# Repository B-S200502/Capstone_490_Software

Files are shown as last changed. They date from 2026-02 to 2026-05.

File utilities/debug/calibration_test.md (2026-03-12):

# Camera–array calibration test setup

Reference for the physical layout used when testing heatmap vs camera alignment. Values are also in [config.py](../../src/software/acoustic_imager/config.py) as `CALIBRATION_*` for use in code.

## Layout

- **Camera on left**, **audio board (mic array) on right**; **same heading** (parallel).
- Camera optical axis and array “forward” (0°) are parallel; offset between them is lateral only.

## Distance

- **5 inches** — distance from camera to mic array center (depth).
- Measured along the common heading (perpendicular to the camera sensor plane).

## Lateral offset

- **7 inches** — from **camera optical center** to **center of audio board** (array center), in the plane at that depth.
- **Sign convention:** Positive = array center is to the **right** of camera center when the camera is on the left. So in this setup the array is +7 in from camera center.

## Units

- All values in **inches** here and in config for the test setup.
- Conversion to meters or to **pixels** (for overlay alignment) will need camera FOV and sensor/resolution; not defined in this doc.

## Use

- For calibration tests and for future overlay code that maps heatmap angle space to camera pixels (so the blob for the array appears over the array in the image).

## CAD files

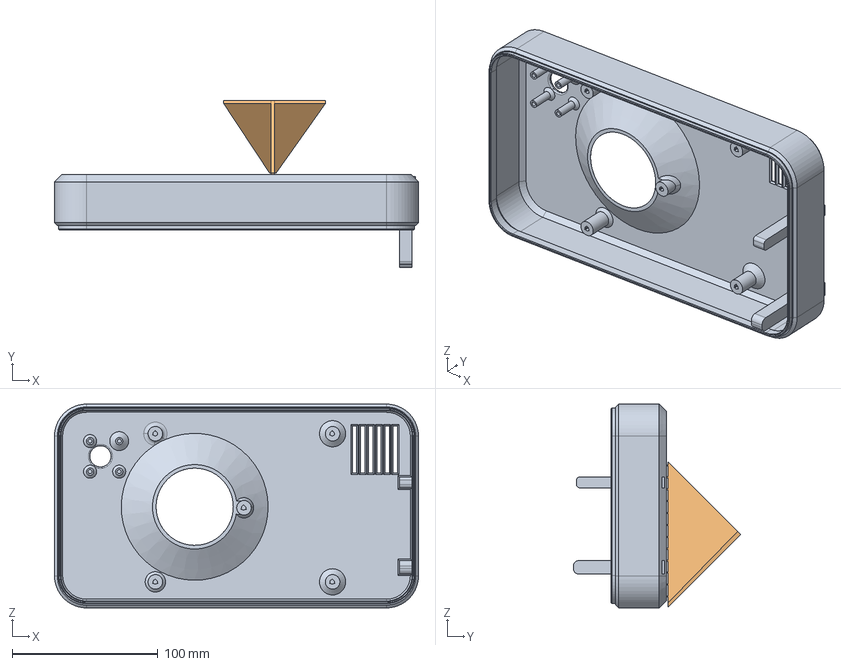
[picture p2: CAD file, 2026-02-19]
hardware/3D_Design/before_printing/BACK_TESTING.FCStd
250.0 x 114.9 x 140.0 mm
final_base_cut

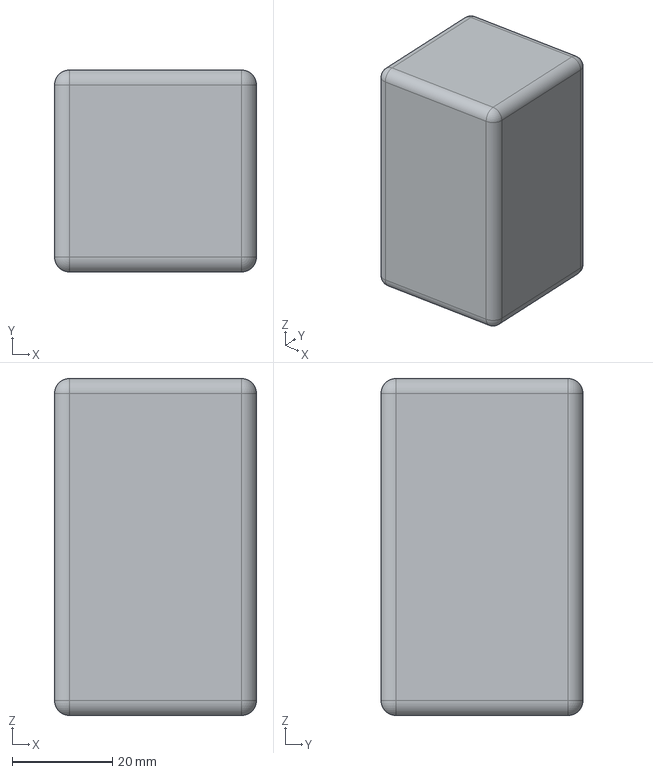
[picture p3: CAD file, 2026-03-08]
hardware/3D_Design/component_step_files/generic_BatteryPack_Envelope.step
40.4 x 40.4 x 67.4 mm

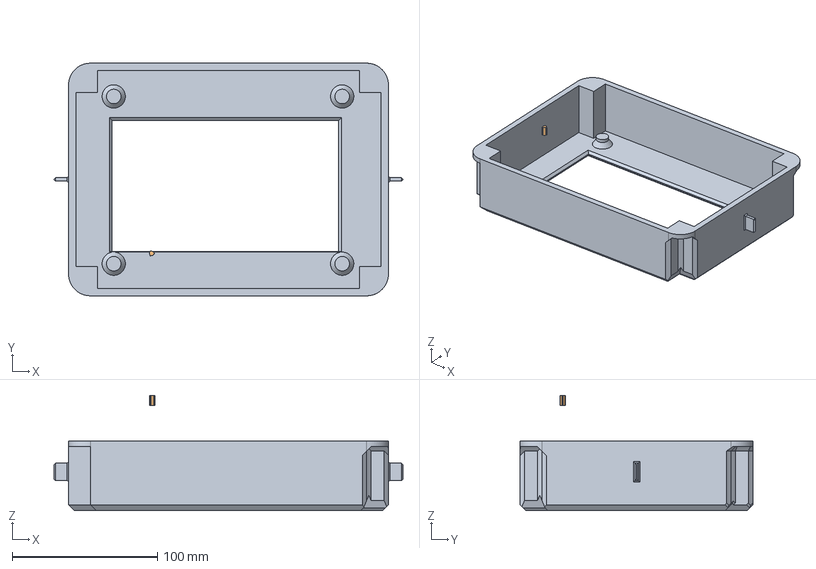
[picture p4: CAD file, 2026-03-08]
hardware/3D_Design/Imager.FCStd
240.0 x 160.0 x 79.3 mm
Front
M3_Screw002

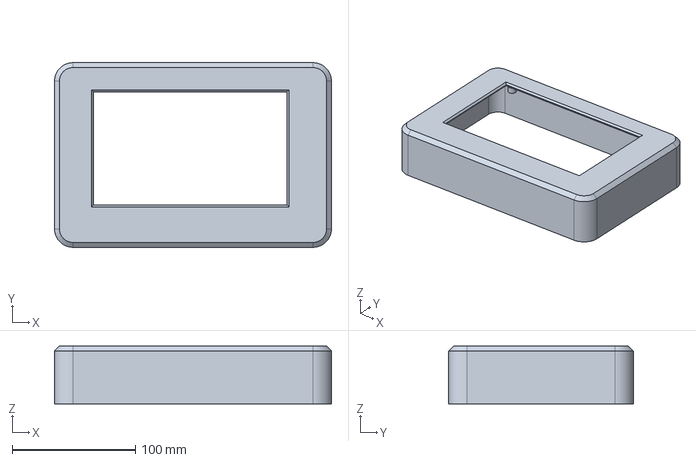
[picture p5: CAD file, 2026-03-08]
hardware/3D_Design/just_in_case_saves/V2_AC.FCStd
225.0 x 150.0 x 47.0 mm
Front
M3_Screw002

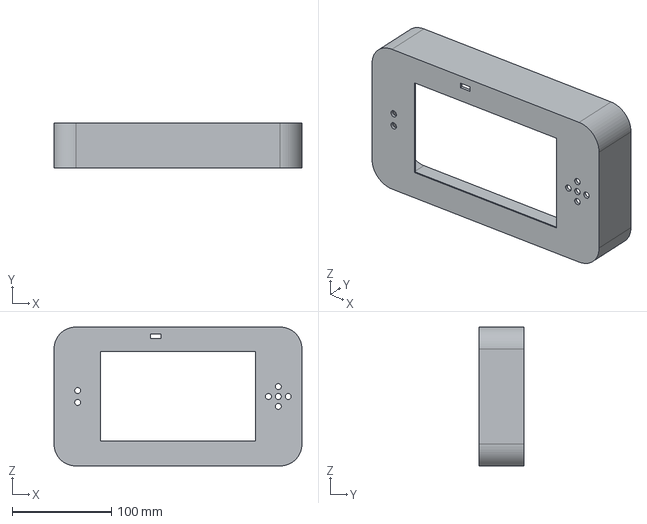
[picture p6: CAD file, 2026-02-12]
hardware/3D_Design/result_step_files/TOP-or-FRONT-AcousticImager-Fusion001.step
250.0 x 45.0 x 140.0 mm

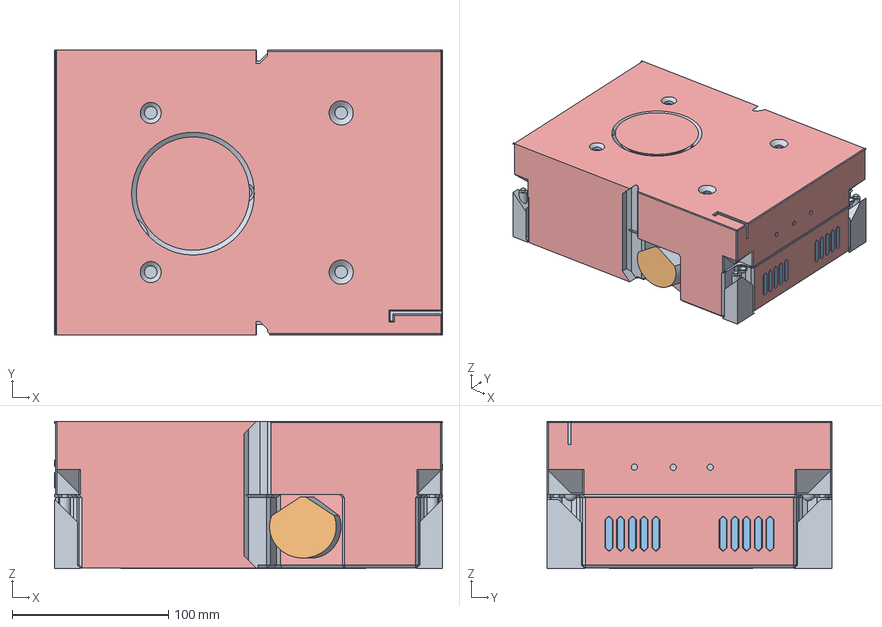
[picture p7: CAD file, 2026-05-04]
src/hardware/for_airflow/airflow.FCStd
248.0 x 182.0 x 94.0 mm
inlet
outlet
outlet001
wall

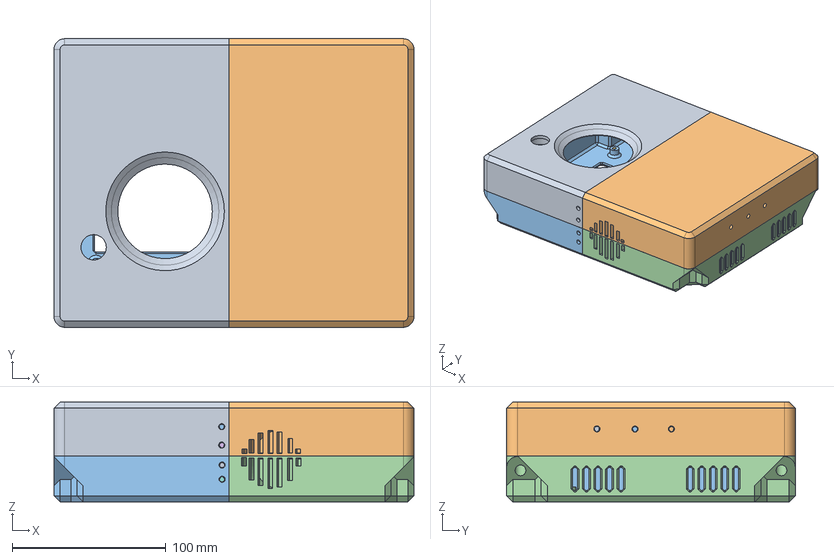
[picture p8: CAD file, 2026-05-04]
src/hardware/Front_And_Back_File/Quarters_MK3.FCStd
234.5 x 188.0 x 65.0 mm
Bottom_Left
Bottom_Right
Top_Left
Top_Right
M3_Screw_corner_ref__front_001
M3_Screw_corner_ref__front_002
M3_Screw_corner_ref__front_003
M3_Screw_corner_ref__front_004
M3_Screw_audio001
M3_Screw_audio002
M3_Screw_audio003
M3_Screw_audio004
M3_Screw_lcd001
M3_Screw_lcd002
M3_Screw_lcd003
M3_Screw_lcd004
M3_Screw_pi001
M3_Screw_pi002
M3_Screw_pi003
m4_fan_8mm001
m4_fan_8mm002
m4_fan_8mm003
m4_fan_8mm004
M2.6_cam_7mm001
M2.6_cam_7mm002
M2.6_cam_7mm003
M2.6_cam_7mm004
M3_thick_wall001
M3_thick_wall002
M3_thick_wall003
M3_thick_wall004
M3_thick_wall005
M3_thick_wall06
M3_thick_wall07
M3_thick_wall008
M3_Screw_power_wall001
M3_Screw_power_wall002
M3_Screw_power_wall003

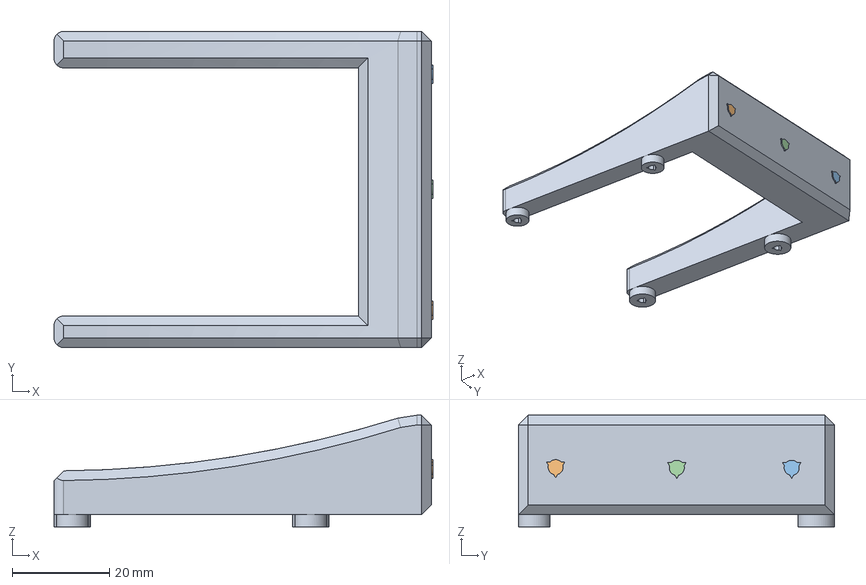
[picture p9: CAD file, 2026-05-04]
src/hardware/Pi_Base/Pi_Base_Support.FCStd
77.9 x 65.0 x 22.9 mm
before_side_screws
M3_Screw_pi001
M3_Screw_pi002
M3_Screw_pi003

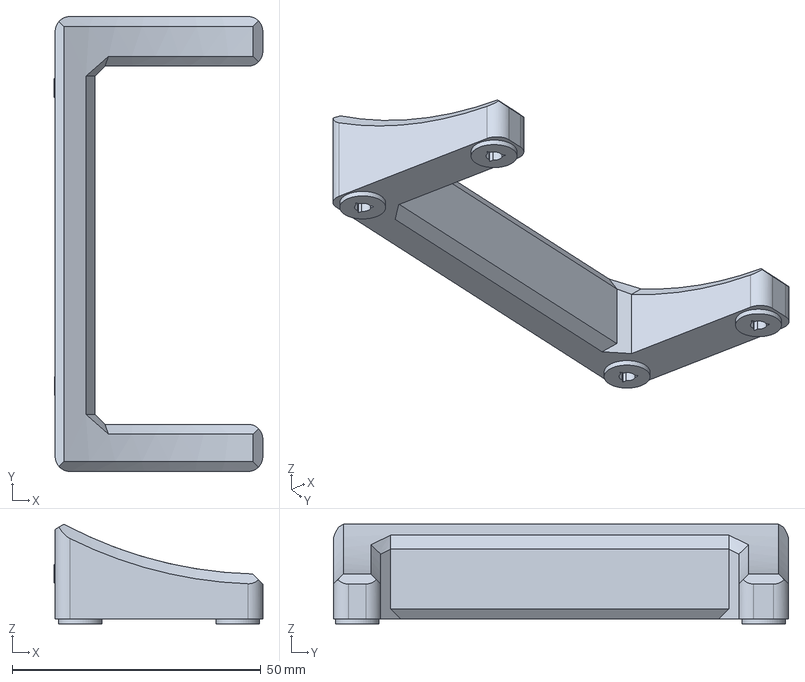
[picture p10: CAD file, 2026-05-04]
src/hardware/Power_Base/PowerBoard_Support_Stand.FCStd
42.0 x 91.5 x 20.0 mm
before_side_wall_screws
M3_Screw_power_wall001
M3_Screw_power_wall002
M3_Screw_power_wall003

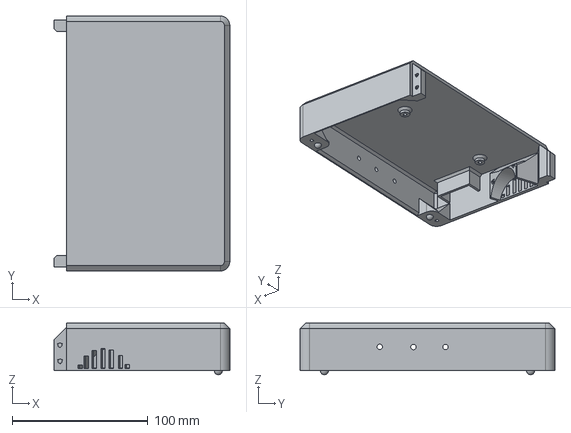
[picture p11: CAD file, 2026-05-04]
src/hardware/result_step_files/bottom/BR_low_fan.step
129.5 x 188.0 x 38.0 mm

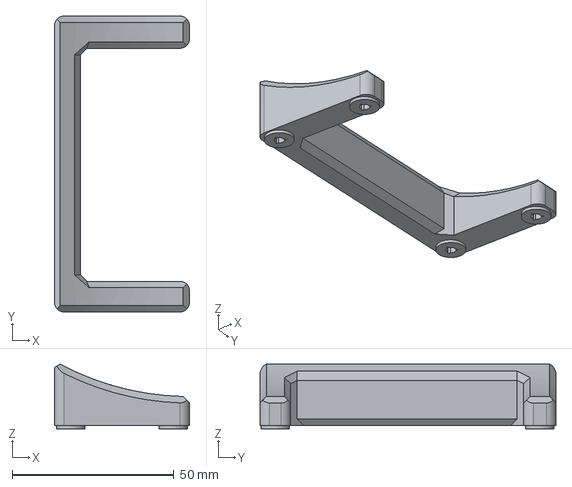
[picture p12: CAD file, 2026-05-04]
src/hardware/result_step_files/power_base/PowerBoard_Support_Stand.step
41.8 x 91.5 x 20.0 mm

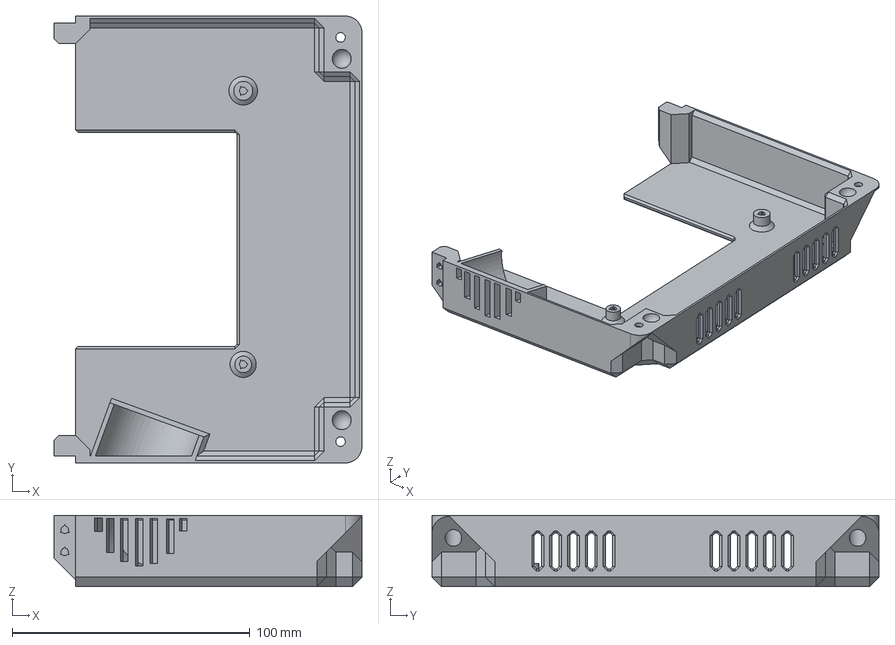
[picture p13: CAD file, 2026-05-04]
src/hardware/result_step_files/top/TR_High_Fan.step
129.5 x 188.0 x 30.0 mm

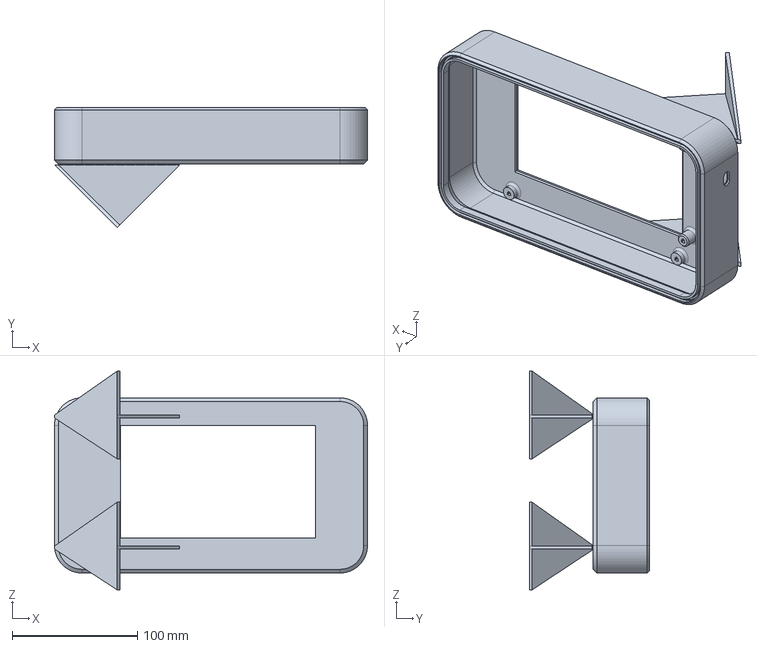
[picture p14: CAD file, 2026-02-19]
hardware/3D_Design/before_printing/FRONT_TESTING.FCStd
250.0 x 95.9 x 174.7 mm

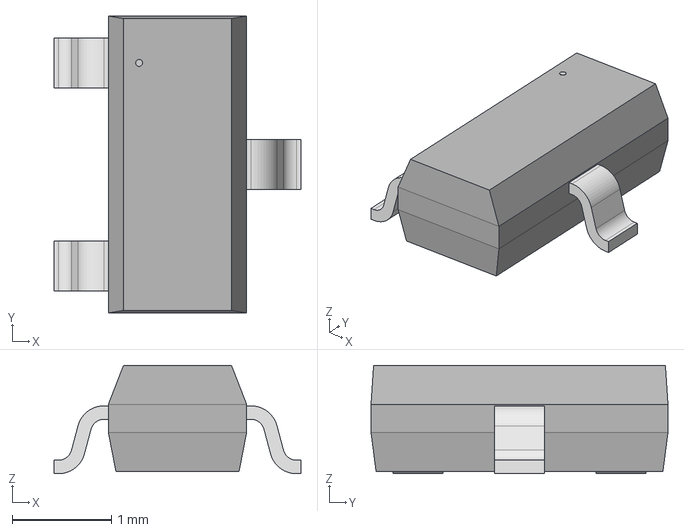
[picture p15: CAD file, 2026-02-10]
hardware/3D_Design/component_step_files/low_level_components/DMN3731U-7_DIO.step
2.49 x 3.00 x 1.09 mm

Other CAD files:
src/hardware/result_step_files/pi/Pi_Base_Support_Cut.step
hardware/3D_Design/component_step_files/pi_camera_g_detailed.step
hardware/3D_Design/just_in_case_saves/V2_AC_test1.FCStd
hardware/3D_Design/result_step_files/BACK-AcousticImager-Fusion001.step
hardware/3D_Design/component_step_files/LQFP100-14x14mm.step
hardware/3D_Design/component_step_files/Power Board.step
hardware/3D_Design/component_step_files/RaspberryPi5.step
hardware/3D_Design/component_step_files/lcd 7inch cap 1024 600.step
hardware/3D_Design/component_step_files/low_level_components/M3.5x8mm Screw Hole Positive-Body.step
hardware/3D_Design/component_step_files/low_level_components/QFP50P2200X2200X160-144N.step
hardware/3D_Design/component_step_files/low_level_components/SPH8878LR5H_1_Accurate.step
hardware/3D_Design/component_step_files/low_level_components/TPH2504-TR.stp
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

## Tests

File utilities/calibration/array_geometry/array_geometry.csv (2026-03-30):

payload_index | mic_label | x_mm | y_mm | x_m | y_m | dist_to_camera_mm | dist_to_center_mm | azimuth_deg | min_dist_mm
0 | U3 | 13.3 | 7.08 | 0.013299999999999998 | 0.007080000000000002 | 37.35 | 15.07 | 28.03 | 37.35
1 | U2 | 23.8 | 4.28 | 0.0238 | 0.004280000000000001 | 30.12 | 24.18 | 10.19 | 30.12
2 | U1 | 1.9 | 8.38 | 0.0018999999999999985 | 0.008380000000000002 | 47.34 | 8.59 | 77.23 | 47.34
3 | U4 | 9.7 | 17.78 | 0.009700000000000002 | 0.01778 | 37.57 | 20.25 | 61.39 | 37.57
4 | U8 | -6.8 | 14.38 | -0.006799999999999997 | 0.014380000000000002 | 54.3 | 15.91 | 115.31 | 54.3
5 | U6 | -11.6 | 1.48 | -0.011600000000000001 | 0.0014800000000000004 | 62.31 | 11.69 | 172.73 | 62.31
6 | U9 | -18.3 | 10.48 | -0.018299999999999997 | 0.010480000000000001 | 66.27 | 21.09 | 150.2 | 66.27
7 | U7 | -2.2 | 22.76 | -0.0022000000000000027 | 0.022760000000000002 | 48.97 | 22.87 | 95.52 | 48.96
8 | U18 | -16.8 | -8.12 | -0.016799999999999995 | -0.008119999999999997 | 70.9 | 18.66 | -154.2 | 70.9
9 | U16 | 7.9 | -9.62 | 0.007899999999999999 | -0.009619999999999997 | 51.06 | 12.45 | -50.61 | 51.06
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

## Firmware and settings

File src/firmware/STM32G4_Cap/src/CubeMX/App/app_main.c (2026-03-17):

/**
 * @file app_main.c
 * @brief Main application entry point for STM32G4 Acoustic Imager project
 * @details This file contains the main application logic and initialization
 */

/* =========================================================================
 * INCLUDES
 * ========================================================================= */
#include <stdlib.h>
#include <string.h>

#include "main.h"
#include "adc.h"
#include "dma.h"
#include "spi.h"
#include "tim.h"
#include "usart.h"
#include "usb_device.h"
#include "gpio.h"

#include "arm_math.h"

#include "app_main.h"

#include "protocol/spi_protocol.h"

#include "transport/spi_stream.h"
#include "transport/spi_stream_test.h"
#include "transport/spi_dma.h"

#include "dsp/dsp_pipeline.h"
#include "dsp/dsp_pipeline_test.h"

#include "usb/usb_debug.h"

#include "metrics/timing.h"



/* =========================================================================
 * DEFINES & CONSTANTS
 * ========================================================================= */
#define ADC_DMA_BUF_SIZE (2 * N_CH_PER_ADC * FRAME_SIZE) // 4096 samples per half-buffer
#define ADC_READY_HALF_MASK ((1u << N_ADCS) - 1u)
#define ADC_READY_FULL_MASK (ADC_READY_HALF_MASK << N_ADCS)
#define PASSTHROUGH_DISABLED_MIC 0xFFu
#define ADC_CLIP_LOW_THRESHOLD 200u
#define ADC_CLIP_HIGH_THRESHOLD 3900u

/* =========================================================================
 * STATIC VARIABLES
 * ========================================================================= */
// Each ADC gets dedicated DMA circular buffer (2 * 4 * 1024 = 8192 samples total)
// Half-buffer = 4096 samples (at 48kHz = 85.2ms)
static uint16_t adc1_buf[ADC_DMA_BUF_SIZE];
static uint16_t adc2_buf[ADC_DMA_BUF_SIZE];
static uint16_t adc3_buf[ADC_DMA_BUF_SIZE];
static uint16_t adc4_buf[ADC_DMA_BUF_SIZE];

static float mic_fft_buffer[FRAME_SIZE];
static float fft_avg[N_MICS][FRAME_SIZE];

// TODO: Test buffer for raw FFT output magnitude calcs, delete or pre-processor guard

static float mag_buffer[FRAME_SIZE/2 + 1];

static arm_rfft_fast_instance_f32 fft_instance;

static spi_stream_t spi_stream_ctx;

static uint32_t _print_counter = 0;
static uint32_t adc_pending_mask = 0;
static uint32_t clip_window_count = 0u;
static uint32_t clip_sample_count = 0u;
static uint16_t battery_millivolts_cached = 0u;

// TODO: sample_rate_hz bug
static uint32_t sample_rate_hz = 0;
#define SAMPLE_RATE_HZ 100000

static struct {
  uint8_t enabled;
  uint8_t mic_index;
} passthrough_state = {0u, PASSTHROUGH_DISABLED_MIC};

static char usb_cmd_buffer[APP_USB_CMD_MAX_LEN];
static uint32_t usb_cmd_length = 0u;

// Ping-pong processing flags
// Bit assignment: [4-7]=Full flags (ADC1-4), [0-3]=Half flags (ADC1-4)
volatile uint32_t adc_ready_mask = 0;
volatile uint8_t fft_in_progress = 0;  // Prevent overlapping FFT calculations

// Track which half of buffer is ready for FFT
// ready_half: 0=first half (0-1023), 1=second half (1024-2047)
volatile uint8_t ready_half[4] = {0};  // One per ADC

// Interrupt counters (for debug / watch)
volatile uint32_t irq_events = 0;            // total ADC IRQ events
volatile uint32_t irq_count_adc[4] = {0};    // per-ADC IRQ counters

/* =========================================================================
 * FORWARD DECLARATIONS
 * ========================================================================= */

/* static void module_init(void); */
/* static void module_process(void); */
static uint32_t app_get_tim6_trigger_hz(void);
static void app_process_synced_window(uint32_t half_offset, uint16_t frame_flags);
static const uint16_t *app_get_adc_buffer(uint8_t adc_index);
static uint16_t app_read_battery_millivolts(void);
static uint16_t app_get_cached_battery_mv(void);
static uint16_t app_scan_time_domain_clipping(uint32_t half_offset);
static void app_send_passthrough_window(uint32_t half_offset, uint32_t sample_rate_hz);
static void app_handle_usb_command(const char *command);

/* =========================================================================
 * PUBLIC FUNCTIONS
 * ========================================================================= */

// TODO: Deprecated
typedef struct {
    uint8_t header;
    uint8_t adc_id;
    uint32_t frame_counter;
    float fft_data[512]; // TODO: Correct MACRO use
    uint16_t checksum;
} __attribute__((packed)) SPI_Packet_t;

void app_init(void) {
  // Initialize FFT instance (precompute twiddle factors, etc.)
  arm_rfft_fast_init_f32(&fft_instance, FRAME_SIZE);

  // Initialize FFT performance measurement
  init_fft_performance_measurement();
  
  spi_stream_init(&spi_stream_ctx);
}


void app_start(void) {

  // Any additional startup logic can go here
  HAL_Delay(1000);  // Wait for peripherals to stabilize

  // Default LOW gain; then follow Pi's AUTO_GAIN_CNTL (no command yet = pull-down = LOW)
  HAL_GPIO_WritePin(GAIN_CNTL_GPIO_Port, GAIN_CNTL_Pin, GPIO_PIN_RESET);
  GPIO_PinState auto_gain = HAL_GPIO_ReadPin(AUTO_GAIN_CNTL_GPIO_Port, AUTO_GAIN_CNTL_Pin);
  HAL_GPIO_WritePin(GAIN_CNTL_GPIO_Port, GAIN_CNTL_Pin, (auto_gain == GPIO_PIN_SET) ? GPIO_PIN_SET : GPIO_PIN_RESET);

  // Calibrate all ADCs before use
  HAL_ADCEx_Calibration_Start(&hadc1, (uint32_t)ADC_SINGLE_ENDED);
  HAL_ADCEx_Calibration_Start(&hadc2, (uint32_t)ADC_SINGLE_ENDED);
  HAL_ADCEx_Calibration_Start(&hadc3, (uint32_t)ADC_SINGLE_ENDED);
  HAL_ADCEx_Calibration_Start(&hadc4, (uint32_t)ADC_SINGLE_ENDED);
  HAL_ADCEx_Calibration_Start(&hadc5, (uint32_t)ADC_SINGLE_ENDED);


  // Start Timer6 (triggers all ADCs synchronously)
  HAL_TIM_Base_Start(&htim6);
  HAL_Delay(1000);

  sample_rate_hz = app_get_tim6_trigger_hz();
  // Start all 4 ADCs with DMA (2048 samples = 1024×2 ping-pong)
  HAL_ADC_Start_DMA(&hadc1, (uint32_t*)adc1_buf, (uint32_t)(ADC_DMA_BUF_SIZE));
  HAL_ADC_Start_DMA(&hadc2, (uint32_t*)adc2_buf, (uint32_t)(ADC_DMA_BUF_SIZE));
  HAL_ADC_Start_DMA(&hadc3, (uint32_t*)adc3_buf, (uint32_t)(ADC_DMA_BUF_SIZE));
  HAL_ADC_Start_DMA(&hadc4, (uint32_t*)adc4_buf, (uint32_t)(ADC_DMA_BUF_SIZE));

  usb_dbg_init(16, 200);  // avg over 16 prints, print every 200 ms

}

/**
 * @brief Main application loop
 * @return void
 */
void app_loop(void) {
  // Poll Pi gain control: read AUTO_GAIN_CNTL and set GAIN_CNTL to match (HIGH/LOW gain)
  GPIO_PinState auto_gain = HAL_GPIO_ReadPin(AUTO_GAIN_CNTL_GPIO_Port, AUTO_GAIN_CNTL_Pin);
  HAL_GPIO_WritePin(GAIN_CNTL_GPIO_Port, GAIN_CNTL_Pin, (auto_gain == GPIO_PIN_SET) ? GPIO_PIN_SET : GPIO_PIN_RESET);

  // Main application loop - check for ADC data ready and process
#if MODE == DEBUG
  if (_print_counter++ >= 1000) {
    _print_counter = 0;
    usb_printf("Main loop heartbeat\r\n");

        
    // Report FFT performance
    usb_printf("FFT Avg Cycles: %d.%02d\r\n", PRINT_F2(get_fft_avg_cycles()));
    usb_printf("FFT Last Cycles: %d.%02d\r\n", PRINT_F2(get_fft_last_cycles()));
  }
#endif

  __disable_irq();
  adc_pending_mask |= adc_ready_mask;
  adc_ready_mask = 0;
  __enable_irq();

  if ((adc_pending_mask & ADC_READY_HALF_MASK) == ADC_READY_HALF_MASK) {
    adc_pending_mask &= ~ADC_READY_HALF_MASK;

    if (!fft_in_progress) {
      app_process_synced_window(0u, SPI_FRAME_FLAG_SYNCED_ALL_MICS);
    }
    return;
  }

  if ((adc_pending_mask & ADC_READY_FULL_MASK) == ADC_READY_FULL_MASK) {
    adc_pending_mask &= ~ADC_READY_FULL_MASK;
    
    if (!fft_in_progress) {
      app_process_synced_window(ADC_DMA_BUF_SIZE / 2u,
                                (uint16_t)(SPI_FRAME_FLAG_SYNCED_ALL_MICS |
                                           SPI_FRAME_FLAG_SECOND_HALF));
    }
    return;
  }
}


  /* Periodic debug print of IRQ counters over UART (every ~1000 iterations) */
  

void test_spi_stream_loop(void) {
  HAL_Delay(1000);
  // spi_stream_unit_test_build_packet();
  // spi_stream_unit_test_nulls();
  // spi_stream_unit_test_small_cap();
  // spi_stream_unit_test_frame_counter();
  // spi_loopback_unit_test();
  spi_loopback_unit_test2();
}

void test_dsp_pipeline_loop(void) {
  HAL_Delay(1000);
  dsp_unit_test_suite();
}

/* ============================================================================
 * STATIC FUNCTIONS
 * ============================================================================ */

/**
 * @brief Static helper function description
 * @return void
 */
static uint32_t app_get_tim6_trigger_hz(void)
{
  uint32_t timer_clock_hz = HAL_RCC_GetPCLK1Freq();

  if ((RCC->CFGR & RCC_CFGR_PPRE1) != RCC_HCLK_DIV1) {
    timer_clock_hz *= 2u;
  }

  return timer_clock_hz / ((htim6.Init.Prescaler + 1u) * (htim6.Init.Period + 1u));
}


static void app_process_synced_window(uint32_t half_offset, uint16_t frame_flags)
{
  // uint32_t sample_rate_hz;
  uint32_t batch_id;
  uint16_t battery_millivolts;
  uint8_t  mic_index;
  size_t   payload_len, final_len;

  uint16_t clipping_hits;

  fft_in_progress = 1u;

  // TODO: Might want to do this once only?
  // sample_rate_hz = app_get_tim6_trigger_hz();
  batch_id = spi_stream_next_batch(&spi_stream_ctx);

#if APP_BATTERY_READ_EVERY_N_FRAMES > 0u
  if ((batch_id % (uint32_t)APP_BATTERY_READ_EVERY_N_FRAMES) == 0u) {
    battery_millivolts_cached = app_read_battery_millivolts();
  }
  battery_millivolts = battery_millivolts_cached;
#else
  battery_millivolts = app_read_battery_millivolts();
#endif

#if APP_CLIP_DETECT_ENABLE
  clipping_hits = app_scan_time_domain_clipping(half_offset);

  if (clipping_hits > 0u) {
    frame_flags |= SPI_FRAME_FLAG_TIME_CLIPPING;
    clip_window_count++;
    clip_sample_count += clipping_hits;
  }
#else
  clipping_hits = 0u;
#endif

#if MODE != RELEASE && APP_CLIP_DETECT_ENABLE
  usb_printf("Clipping hits in window: %u, total clipped windows: %u, total clipped samples: %u\r\n",
             clipping_hits, clip_window_count, clip_sample_count);
#endif

#if MODE != RELEASE
usb_printf("Battery millivolts: %u mV\r\n", battery_millivolts);
usb_printf("Raw Battery millivolts: %u mV\r\n", (uint16_t)(battery_millivolts/BATT_DIVIDER_NUMERATOR));
#endif


  // Keep mic_index and set to 16 for now
  mic_index = N_MICS;
  payload_len = N_MICS * SPI_MIC_PAYLOAD_BYTES;
  final_len = 0;

  // Need to check here if SPI is done transmitting before starting next batch
  // Use pending flag with spi_dma_done flag?

  // Process all mics: FFT + bin average (no per-mic append)
  for (uint8_t adc = 0; adc < N_ADCS; adc++) {
    uint16_t *active_half = (uint16_t *)(app_get_adc_buffer(adc) + half_offset);

    for (uint8_t channel = 0; channel < N_CH_PER_ADC; channel++) {
      uint8_t mic_idx = adc * N_CH_PER_ADC + channel;
      process_adc_channel_pipeline(&fft_instance,
                                   active_half,
                                   channel,
                                   mic_fft_buffer);
      update_fft_bin_average(fft_avg[mic_idx], mic_fft_buffer, FRAME_SIZE, FFT_BIN_AVG_BETA);
    }
  }

  if (get_spi_dma_busy()) {
    fft_in_progress = 0u;
    return;
  }

  uint8_t *tx_buf = spi_dma_get_tx_buffer();
  size_t offset = 0;
  // Fill the header once

  offset += spi_stream_build_frame_header(&spi_stream_ctx,
                                          tx_buf,
                                          SPI_FRAME_PACKET_SIZE_BYTES,
                                          batch_id,
                                          mic_index,
                                          FRAME_SIZE,
                                          SAMPLE_RATE_HZ,
                                          (uint16_t)(frame_flags | SPI_FRAME_FLAG_PAYLOAD_COMPLEX | SPI_FRAME_FLAG_BATTERY_VALID),
                                          payload_len,
                                          battery_millivolts);

  if (offset == 0) {
    // Failed to build header, skip this batch
    fft_in_progress = 0u;
    return;
  }

  // One full bulk copy of entire payload (fft_avg is contiguous; size is fixed at build time)
  memcpy(tx_buf + offset, &fft_avg[0][0], SPI_FRAME_PAYLOAD_BYTES);
  offset += SPI_FRAME_PAYLOAD_BYTES;

  // Finalize (append checksum if enabled) and send
  final_len = spi_stream_finalize_frame(tx_buf,
                                        SPI_FRAME_PACKET_SIZE_BYTES - offset,
                                        offset);
  
  if (final_len == 0u) {
    fft_in_progress = 0u;
    return;
  }

  spi_stream_tx_dma(tx_buf, (uint32_t)final_len);

#if MODE != RELEASE
  usb_dbg_push_adc_window_4adc(&adc1_buf[half_offset],
                               &adc2_buf[half_offset],
                               &adc3_buf[half_offset],
                               &adc4_buf[half_offset],
                               FRAME_SIZE);

  if (passthrough_state.enabled) {
    app_send_passthrough_window(half_offset, sample_rate_hz);
  }
#endif

  fft_in_progress = 0u;
}

static const uint16_t *app_get_adc_buffer(uint8_t adc_index)
{
  switch (adc_index) {
    case 0u: return adc1_buf;
    case 1u: return adc2_buf;
    case 2u: return adc3_buf;
    default: return adc4_buf;
  }
}

static uint16_t app_read_battery_millivolts(void)
{
  uint16_t raw_counts = 0u;
  uint32_t sense_mv;

  if (ADC_ReadBatteryRaw(&raw_counts) != HAL_OK) {
    return 0u;
  }

  sense_mv = ((uint32_t)raw_counts * BATT_ADC_VREF_MV) / 4095u;
  sense_mv = (sense_mv * BATT_DIVIDER_NUMERATOR) / BATT_DIVIDER_DENOMINATOR;
  return (uint16_t)sense_mv;
}

static uint16_t app_get_cached_battery_mv(void)
{
  return battery_millivolts_cached;
}

static uint16_t app_scan_time_domain_clipping(uint32_t half_offset)
{
  uint32_t hits = 0u;

  for (uint8_t adc = 0u; adc < N_ADCS; adc++) {
    const uint16_t *active_half = app_get_adc_buffer(adc) + half_offset;

    for (uint32_t i = 0u; i < FRAME_SIZE; i++) {
      uint32_t base = i * N_CH_PER_ADC;
      for (uint8_t ch = 0u; ch < N_CH_PER_ADC; ch++) {
        uint16_t sample = active_half[base + ch];
        if (sample <= ADC_CLIP_LOW_THRESHOLD || sample >= ADC_CLIP_HIGH_THRESHOLD) {
          hits++;
        }
      }
    }
  }

  if (hits > 0xFFFFu) {
    return 0xFFFFu;
  }

  return (uint16_t)hits;
}

static void app_send_passthrough_window(uint32_t half_offset, uint32_t sample_rate_hz)
{
  uint8_t mic_index = passthrough_state.mic_index;
  uint8_t adc_index;
  uint8_t adc_channel;
  const uint16_t *adc_window;

  if (mic_index >= N_MICS) {
    return;
  }

  adc_index = mic_index / N_CH_PER_ADC;
  adc_channel = mic_index % N_CH_PER_ADC;
  adc_window = app_get_adc_buffer(adc_index) + half_offset;

  usb_dbg_stream_mic_window_csv(mic_index,
                                adc_window,
                                adc_channel,
                                FRAME_SIZE,
                                sample_rate_hz);
}

void app_usb_cdc_rx(const uint8_t *buf, uint32_t len)
{
  if (!buf) {
    return;
  }

  for (uint32_t i = 0; i < len; i++) {
    char ch = (char)buf[i];

    if (ch == '\r') {
      continue;
    }

    if (ch == '\n') {
      usb_cmd_buffer[usb_cmd_length] = '\0';
      app_handle_usb_command(usb_cmd_buffer);
      usb_cmd_length = 0u;
      continue;
    }

    if (usb_cmd_length + 1u < sizeof(usb_cmd_buffer)) {
      usb_cmd_buffer[usb_cmd_length++] = ch;
    } else {
      usb_cmd_length = 0u;
    }
  }
}

static void app_handle_usb_command(const char *command)
{
  unsigned long mic_index;

  if (!command || command[0] == '\0') {
    return;
  }

  if (strcmp(command, "help") == 0) {
    usb_printf("Commands: help, status, battery, clip, clip reset, pass off, pass <0-15>\r\n");
    return;
  }

  if (strcmp(command, "status") == 0) {
    usb_printf("status: pending=0x%02lX passthrough=%s mic=%u battery=%umV rate=%luHz clip_windows=%lu clip_hits=%lu\r\n",
               (unsigned long)adc_pending_mask,
               passthrough_state.enabled ? "on" : "off",
               (unsigned)passthrough_state.mic_index,
               (unsigned)app_get_cached_battery_mv(),
               (unsigned long)app_get_tim6_trigger_hz(),
               (unsigned long)clip_window_count,
               (unsigned long)clip_sample_count);
    return;
  }

  if (strcmp(command, "clip") == 0) {
    usb_printf("clip: windows=%lu hits=%lu thresholds=[<=%u, >=%u]\r\n",
               (unsigned long)clip_window_count,
               (unsigned long)clip_sample_count,
               (unsigned)ADC_CLIP_LOW_THRESHOLD,
               (unsigned)ADC_CLIP_HIGH_THRESHOLD);
    return;
  }

  if (strcmp(command, "clip reset") == 0) {
    clip_window_count = 0u;
    clip_sample_count = 0u;
    usb_printf("clip counters reset\r\n");
    return;
  }

  if (strcmp(command, "battery") == 0) {
    usb_printf("battery=%umV\r\n", (unsigned)app_get_cached_battery_mv());
    return;
  }

  if (strcmp(command, "pass off") == 0) {
    passthrough_state.enabled = 0u;
    passthrough_state.mic_index = PASSTHROUGH_DISABLED_MIC;
    usb_printf("passthrough disabled\r\n");
    return;
  }

  if (strncmp(command, "pass ", 5) == 0) {
    mic_index = strtoul(command + 5, NULL, 10);
    if (mic_index < N_MICS) {
      passthrough_state.enabled = 1u;
      passthrough_state.mic_index = (uint8_t)mic_index;
      usb_printf("passthrough mic=%u enabled\r\n", (unsigned)passthrough_state.mic_index);
    } else {
      usb_printf("invalid mic index, expected 0-%u\r\n", (unsigned)(N_MICS - 1u));
    }
    return;
  }

  usb_printf("unknown command: %s\r\n", command);
}

/* Old app_process_synced_window, can be deleted but leaving for now in case */

// static void app_process_synced_window(uint32_t half_offset, uint16_t frame_flags)
// {
//   // uint32_t sample_rate_hz;
//   uint32_t batch_id;
//   uint16_t battery_millivolts;

//   fft_in_progress = 1u;


//   // TODO: Might want to do this once only?
//   // sample_rate_hz = app_get_tim6_trigger_hz();
//   batch_id = spi_stream_next_batch(&spi_stream_ctx);
//   battery_millivolts = app_read_battery_millivolts();

//   for (uint8_t adc = 0; adc < N_ADCS; adc++) {
//     uint16_t *active_half = (uint16_t *)(app_get_adc_buffer(adc) + half_offset);

//     for (uint8_t channel = 0; channel < N_CH_PER_ADC; channel++) {
//       uint16_t mic_index = (uint16_t)(adc * N_CH_PER_ADC + channel);
//       size_t packet_len;
      
//       process_adc_channel_pipeline(&fft_instance,
//                                    active_half,
//                                    channel,
//                                    mic_fft_buffer);
      
//       // if (_print_counter++ == 100) {
//       // _print_counter = 0;

//       // for (int i = 0; i < FRAME_SIZE; i++) {
//       //   usb_printf("index=%d, value=%d.%02d\r\n",
//       //             i,
//       //             PRINT_F3(mic_fft_buffer[i]));          
//       // }
//       // rfft_packed_to_mag(mic_fft_buffer, mag_buffer, FRAME_SIZE);
//       // dsp_print_fft_report(SAMPLE_RATE_HZ, mag_buffer, FRAME_SIZE);
//       // }
     
      
//       uint8_t *tx_buf = spi_dma_get_tx_buffer();

//       packet_len = spi_stream_build_mic_packet(
//           &spi_stream_ctx,
//           tx_buf,
//           SPI_PACKET_SIZE,
//           batch_id,
//           mic_index,
//           mic_fft_buffer,
//           FRAME_SIZE,
//           sample_rate_hz,
//           (uint16_t)(frame_flags | SPI_FRAME_FLAG_PAYLOAD_COMPLEX | SPI_FRAME_FLAG_BATTERY_VALID),
//           battery_millivolts);

//       if (packet_len > 0u) {
//         // spi_stream_tx_blocking(spi_tx, packet_len);
//         spi_stream_tx_dma(tx_buf, packet_len);
//       }
//     }
//   }

//   usb_dbg_push_adc_window_4adc(&adc1_buf[half_offset],
//                                &adc2_buf[half_offset],
//                                &adc3_buf[half_offset],
//                                &adc4_buf[half_offset],
//                                FRAME_SIZE);

//   if (passthrough_state.enabled) {
//     app_send_passthrough_window(half_offset, sample_rate_hz);
//   }

//   fft_in_progress = 0u;
// }
  

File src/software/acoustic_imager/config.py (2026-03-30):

# config.py
"""
Central configuration/constants for the Acoustic Imager software.

Layout: core/UI/heatmap display first; then SIM (SRC: SIM + SRC: LOOP);
then Real hardware (SRC: HW) — SPI transport and heatmap pipeline.
Default source on startup is HW.
"""

from __future__ import annotations

import os
import struct
from pathlib import Path

import numpy as np

# ===============================================================
# 1. Configuration
# ===============================================================
WINDOW_NAME = "Fermat Heatmap (SIM + SPI LOOPBACK) + Bandpass (MUSIC)"
N_MICS = 16
SAMPLES_PER_CHANNEL = 512

SAMPLE_RATE_HZ = 100000
SPEED_SOUND = 343.0
NOISE_POWER = 0.0005   # SIM source only (synthetic noise floor)

WIDTH = 1024
HEIGHT = 600
ALPHA = 0.7
# Single knob: menu button, dropdown items, top HUD pills, bottom HUD pills (0–1; higher = more opaque)
HUD_MENU_OPACITY = 0.92
BUTTON_ALPHA = HUD_MENU_OPACITY  # used by Button.draw for menu dropdown and back button
BUTTON_HITPAD_PX = 14

# Shared UI blue (BGR) for menu, HUD
MENU_ACTIVE_BLUE = (130, 82, 32)       # slightly darker blue
MENU_ACTIVE_BLUE_LIGHT = (165, 110, 48)  # gradient end

# Gallery Action surfaces style: "neon" (dark fill + neon edges) or "classic" (white on blue, pre-neon)
GALLERY_ACTION_STYLE = "classic"

# Single point of control for action button neon glow (0=off, ~0.32=default, 1=full)
ACTION_BTN_GLOW = 0.1

# Storage bar: one glow amount for all subelements (label, ring glow, % text, Used/Free); 0=off
STORAGE_BAR_GLOW = 0.28
STORAGE_BAR_BRIGHTNESS = 1.15
ACTION_BTN_BORDER_THICKNESS = 1

# Gallery action buttons: dark fill + neon edge (BGR) — used when GALLERY_ACTION_STYLE == "neon"
ACTION_BTN_FILL_DARK_TOP = (58, 58, 52)   # dark grey (slightly towards black)
ACTION_BTN_FILL_DARK_BOT = (32, 32, 28)   # darker grey
# Neon border color (electric blue) and glow strength (0=off, ~0.4=visible)
ACTION_BTN_NEON_BORDER_BGR = (255, 210, 100)  # BGR bright cyan-blue
ACTION_BTN_NEON_GLOW = 0.1                # border glow strength
ACTION_BTN_FILL_ALPHA = 1
ACTION_BTN_MODAL_FILL_ALPHA = 1
# Glassy shine on action buttons (0=off, ~0.11=subtle)
ACTION_BTN_SHINE_ALPHA = 0.05

# Classic style (when GALLERY_ACTION_STYLE == "classic"): white on blue, same as pre-neon
# Closed buttons (dock rows): darker blue gradient. Expanded (strip + panel after growth): lighter blue.
CLASSIC_ACTION_FILL_DARK_TOP = (90, 56, 22)   # BGR darker blue — closed dock rows
CLASSIC_ACTION_FILL_DARK_BOT = (115, 77, 34)   # darker blue bottom
CLASSIC_ACTION_FILL_TOP = (130, 82, 32)        # BGR lighter blue — expanded strip/panel (MENU_ACTIVE_BLUE)
CLASSIC_ACTION_FILL_BOT = (165, 110, 48)      # lighter blue bottom (MENU_ACTIVE_BLUE_LIGHT)
CLASSIC_ACTION_TEXT_BGR = (255, 255, 255)     # white text on blue
CLASSIC_ACTION_BORDER_BGR = (255, 255, 255)  # white border
CLASSIC_ACTION_GLOW = 0.06                 # very minor text/icon glow (0=off)

# Freq bar / bandpass: lighter neon blue so it stands out on dark bar
FREQ_BAR_BLUE = (230, 170, 80)
# Gallery filter/sort modal: goldish yellow for selected option (bandpass-style accent)
MODAL_ACTIVE_GOLD = (0, 200, 255)  # BGR goldish yellow

# Dock and content area gradients (BGR grey to black)
DOCK_GRADIENT_TOP = (55, 55, 55)
DOCK_GRADIENT_BOT = (20, 20, 20)
# Slightly darker for grid view and individual viewer background
BG_GRADIENT_TOP = (42, 42, 42)
BG_GRADIENT_BOT = (10, 10, 10)

FREQ_BAR_WIDTH = 150
DB_BAR_WIDTH = 80

# FPS defaults (MENU controls 30/60/MAX at runtime)
FPS_TARGET = 60
FPS_MODE_TO_TARGET = {"30": 30, "60": 60}

# Camera
CAMERA_INDEX = 0
CAMERA_WIDTH = WIDTH
CAMERA_HEIGHT = HEIGHT
USE_CAMERA = True
USE_LIBCAMERA = True

# Camera post-processing
CAMERA_BRIGHTNESS_ALPHA = 1.20   # contrast multiplier (1.0 = no change)
CAMERA_BRIGHTNESS_BETA  = 15      # brightness offset (-100 to +100 typical)
DETECTION_BOX_COLOR = (0, 215, 255)
#DETECTION_BOX_COLOR = (150, 180, 0) #teal
#DETECTION_BOX_COLOR = (0, 200, 200) # yellow

# Bandpass
F_DISPLAY_MAX = 45000.0
F_MIN_HZ_DEFAULT = 24000.0
F_MAX_HZ_DEFAULT = 35000.0
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

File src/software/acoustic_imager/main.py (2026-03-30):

#!/usr/bin/env python3
"""
Acoustic Imager - Main Application

A real-time acoustic beamforming visualization system that supports:
- SIM (simulated) and SPI (hardware) data sources
- Interactive bandpass filtering
- MUSIC beamforming algorithm
- Camera background overlay
- Video recording and screenshots
- Configurable FPS and gain modes

This is the main entry point that orchestrates all modules.
"""

from __future__ import annotations

import logging
import sys
import time

log = logging.getLogger(__name__)
import json
from pathlib import Path
from typing import Optional

import numpy as np
import cv2
import os

# ===============================================================
# Display Configuration for SSH/Headless Operation
# ===============================================================
# Uncomment ONE of these if running over SSH:
# os.environ['DISPLAY'] = ':0'              # Use local display on Pi (monitor attached)
# os.environ['QT_QPA_PLATFORM'] = 'offscreen'  # Headless mode (no display, recording only)

# ===============================================================
# Import modularized components
# ===============================================================
from acoustic_imager import config
from acoustic_imager import state
from acoustic_imager.custom_types import LatestFrame, SourceStats

# Data sources
from acoustic_imager.sources.sim_source import SimSource
from acoustic_imager.sources.spi_source import SPISource
from acoustic_imager.sources.spi_loopback_source import SPILoopbackSource
from acoustic_imager.io.spi_manager import SPIManager
from acoustic_imager.io.gain_control import GAIN_CONTROL


# DSP modules
from acoustic_imager.dsp.beamforming import (
    directivity_ratio,
    music_spectrum,
    music_spectrum_2d,
    music_spectrum_2d_refined,
    music_2d_peak_angles,
    music_2d_second_peak_angles,
)
from acoustic_imager.dsp.heatmap import (
    spectra_to_heatmap_absolute,
    spectra_to_blob_state,
    build_w_lut_u8,
    blend_heatmap_left,
    draw_crosshairs,
    find_local_max,
    percentile_uint8_fast,
    CROSSHAIR_TRACK_RADIUS,
    CROSSHAIR_DISMISS_RADIUS_PX,
)
from acoustic_imager.dsp.bars import (
    draw_db_colorbar,
    freq_to_y,
    y_to_freq,
)
from acoustic_imager.dsp.spectrum_ruler import BAR_MARGIN_RIGHT, FREQ_RULER_WIDTH, RULER_HEIGHT
from acoustic_imager.dsp.spectrum_analyzer import (
    draw_spectrum_analyzer,
    spectrum_cursor_x_to_rel_db,
)

from acoustic_imager.system_info import get_system_network_info
from acoustic_imager.ui.top_hud import draw_hud, handle_hud_click
from acoustic_imager.ui.bottom_hud import draw_bottom_hud, BOTTOM_HUD_HEIGHT
from acoustic_imager.state import HUD

# I/O managers
from acoustic_imager.io.camera_manager import CameraManager
from acoustic_imager.io.gallery_metadata import load_metadata
from acoustic_imager.io.heatmap_stability import apply_heatmap_stability_preset

# UI components (flat modules alongside hud and video_recorder)
from acoustic_imager.state import button_state
from acoustic_imager.ui.button import (
    buttons,
    menu_buttons,
    init_buttons,
    init_menu_buttons,
    update_button_states,
    draw_buttons,
    FPS_MODE_TO_TARGET,
)
from acoustic_imager.ui.screenshot import save_screenshot, draw_screenshot_flash
from acoustic_imager.ui.menu import draw_menu, get_recording_timestamp_rect, _MENU_DROPDOWN_KEYS
from acoustic_imager.ui.gallery import draw_gallery_view, get_gallery_items
from acoustic_imager.ui.handlers import (
    handle_button_click,
    handle_gallery_click,
    handle_gallery_mouse,
    handle_gallery_viewer_mouse,
    handle_email_modal_click,
)
from acoustic_imager.ui.wifi_modal import draw_wifi_modal, handle_wifi_modal_click, handle_wifi_modal_touch_drag
from acoustic_imager.io.magnetometer import MagnetometerReader, probe_i2c_magnetometer
from acoustic_imager.io.compass_calibration import (
    apply_loaded_calibration_to_config,
    clear_user_calibration,
    save_calibration,
    solve_from_samples,
)
from acoustic_imager.io.config_persist import save_mag_heading_display_offset_deg
from acoustic_imager.io.mic_gain_calibration import apply_mic_gain_calibration_json
from acoustic_imager.io.gps_reader import GPSReader
from acoustic_imager.io.position_manager import PositionManager
from acoustic_imager.io.directional_history_store import DirectionalHistoryStore
from acoustic_imager.ui.settings_modal import (
    draw_settings_modal,
    handle_settings_modal_click,
    handle_settings_modal_mouse,
    handle_settings_modal_scroll,
)
from acoustic_imager.ui.calibration_suite_modal import (
    draw_calibration_suite_modal,
    handle_calibration_suite_modal_click,
    handle_calibration_suite_modal_mouse,
    handle_calibration_suite_modal_scroll,
)
from acoustic_imager.ui.acoustic_radar_map import draw_radar_map_widget, update_detection_history
from acoustic_imager.ui.video_recorder import VideoRecorder
from acoustic_imager.ui.battery_icon import (
    draw_battery_icon_for_view,
    load_persisted_battery_state,
    resolve_battery_display_percent,
    save_persisted_battery_state,
)

# region agent log
_AGENT_DEBUG_LOG_PATH = "/home/acousticlord/Capstone_490_Software/.cursor/debug-a9e491.log"
_AGENT_DEBUG_SESSION = "a9e491"


def _agent_debug_log(
    run_id: str,
    hypothesis_id: str,
    location: str,
    message: str,
    data: dict,
) -> None:
    try:
        payload = {
            "sessionId": _AGENT_DEBUG_SESSION,
            "runId": run_id,
            "hypothesisId": hypothesis_id,
            "location": location,
            "message": message,
            "data": data,
            "timestamp": int(time.time() * 1000),
        }
        with open(_AGENT_DEBUG_LOG_PATH, "a", encoding="utf-8") as _f:
            _f.write(json.dumps(payload, separators=(",", ":")) + "\n")
    except Exception:
        pass
# endregion

# ===============================================================
# External dependencies (from parent directories)
# Optional - provide fallbacks if not available
# ===============================================================
try:
    sys.path.append(str(Path(__file__).resolve().parents[1] / "dataframe"))
    from fftframe import FFTFrame  # type: ignore
except ImportError:
    # Fallback: minimal FFTFrame stub
    class FFTFrame:
        def __init__(self):
            self.channel_count = 0
            self.sampling_rate = 0
            self.fft_size = 0
            self.frame_id = 0
            self.fft_data = None

try:
    from heatmap_pipeline_test import create_background_frame  # type: ignore
except ImportError:
    # Fallback: create simple gradient background
    def create_background_frame(width: int, height: int) -> np.ndarray:
        """Create a simple gradient background."""
        bg = np.zeros((height, width, 3), dtype=np.uint8)
        for y in range(height):
            val = int(20 + (y / height) * 30)
            bg[y, :] = (val, val, val)
        return bg
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

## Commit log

2026-02-10 unsized to sketch yet
    [AcousticImager_v8_3_rebuild1 - Copy.FCStd]
2026-02-10 sketch sized
    - screen doesnt fit
    - need battery space (will change battery shape too)
    - moved components around again.
    - need to make port holes, the grips.
    [AcousticImager_v8_3_rebuild1 - Copy.FCStd, AcousticImager_v9.FCStd]
2026-02-10 lcd fits
    - will work on ports
    - will make the button holes
    - will make the side grips at the end
    [AcousticImager.FCStd, AcousticImager_v9.FCStd]
2026-02-12 making ports
    [AcousticImager.FCStd]
2026-02-12 port holes, lcd ok
    - making the "walls" to mount/keep components in place.
    - making the sd card port.
    [AcousticImager.FCStd]
2026-02-12 bottom layer mounting, buttons
    Should be a good save here for now.
    need to see how it will be IRL to make changes and check in with team.
    [AcousticImager.FCStd]
2026-02-12 step files for printing
    [BACK-AcousticImager-Fusion001.step, TOP-or-FRONT-AcousticImager-Fusion001.step]
2026-02-13 Create M3.5x8mm Screw Hole Positive-Body.step
    [M3.5x8mm Screw Hole Positive-Body.step]
2026-02-15 measurements for countersink
    [AcousticImager.FCStd]
2026-02-16 Tree Restructure, platform, counterskin
    - next: raspi positioning
    - ports
    - screws
    - check with team about battery
    - shark fins for 45 deg
    [AcousticImager.FCStd]
2026-02-17 BACK SHARK FIN, components repositioning
    - scews
    - raspi offsetwall+standoofs
    - audio pcb standoffs
    - fix lcd window
    - thicken the countersink
    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
2026-02-18 posts, enchanced countersink
    - lcd posts
    - raspi wall/posts
    - chamfering/filleting stuff/edges
    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
2026-02-18 long list check details
    - made the posts
    - used chamfers/fillets on every edge i could find
    - raspi temp solution until meeting tmr (do need to edit the support walls a bit)
    - lcd fixed
    - ports done (except raspi but its ok - easy)
    - added temp support to the front side
    must do:
    - carve in like 60 screws on the posts
    - fix up raspi a bit
2026-02-18 just in case save
2026-02-18 fixed up raspi a bit
    - waiting for meeting tmr.
    - do the screwwwsss
2026-02-19 final touches stages of the design
    - the TESTING files are files where i exported the NEAR-ENDING FINAL design from the usual "acounsticImager" file. do the screw holes edits, ONLY THEN DO U CHAMFER OR FILLER THE THING!!!!!!!!!
    dont forget the fins
    [BACK_TESTING.FCStd, BEFORE_CUT_AcousticImager.FCStd, FRONT_TESTING.FCStd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]
2026-03-08 updated design (mostly started on external)
    - inner things mostly done and just being finalized through meetings
    - working on handling, connecting, grip, and comfy
    - still need an actual fan and battery pack
    - will see if we will add extension grips instead of embedded
    - make handstraps too
    [AcousticImager.FCStd, BEFORE_CUT_AcousticImager.FCStd, DMN3731U-7_DIO.step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]
2026-03-08 safe save for handles
    [Imager.FCStd]
2026-03-10 power, cam, & pi supports
    - finished up and made some edits for previous things.
    - cam just needs to be finalized for the cam wall and posts after i get proper measurements
    - power and pi should be good, just need chamfers at the end.
    - starting on fan.
    [Imager.FCStd, LQFP100-14x14mm.step, M3.5x8mm Screw Hole Positive-Body.step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]
2026-03-11 before chamfer and screw holes
    [Imager.FCStd, Inverse_body_cut_for_airflow.FCStd, PowerBoard_Support_Stand.FCStd]
2026-03-12 after chamfer corners, before side vents
    [AcousticImager.FCStd, Imager.FCStd, Imager_smth.FCStd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]
2026-03-12 final BEFORE CUTTING SCREWS IN
2026-03-12 one more last push hopefully
    - to fix the thickess of walls and depth of screws
    - make switch
    - changign lip
    [Inverse_body_cut_for_airflow.FCStd, PowerBoard_Support_Stand-Cut.step, PowerBoard_Support_Stand-Cut.stl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]
2026-03-13 printing to test
    [Acoustic_Imager_4.0-Cut_BACK.step, Acoustic_Imager_4.0-Cut_BACK.stl, Acoustic_Imager_4.0-Cut_FRONT.step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]
2026-03-13 folder cleanup
    [BACK_TESTING.FCStd, FRONT_TESTING.FCStd, PowerBoard_Support_Stand-Cut.step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]
2026-03-15 splitting housing into 4 parts, made base for pi, removing unneeded files
    [AC_Bottom_Right_Cut.step, AC_Bottom_Right_Cut.stl, Acoustic_Imager_4.0-Cut_BACK.step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]
2026-03-16 updating final tweaks
    [AC_Bottom_Right_Cut.step, AC_Bottom_Right_Cut.stl, Pi_Base_Support-Cut.step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]
2026-03-16 adding my progress to basem_branch
    [calibration_suite_cal_dump.txt]
2026-03-16 fixed cam screw positions vertically
    [Quarters-Cut_BL_CounterSink.step, Quarters-Cut_BL_CounterSink.stl, Quarters.FCStd]
2026-03-16 updating hardware changes and fixing folder structure for hardware
    Mainly:
    - made the housing 4 quarters
    - fan internal support
    - camera closer to pi
    [Acoustic_Imager_4.0-Cut_BACK.step, Acoustic_Imager_4.0-Cut_BACK.stl, Acoustic_Imager_4.0-Cut_FRONT.step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]
2026-03-16 Updated the UI for the screen calibration
2026-03-16 finalized the screen calibration, wifi, and updated the geometry here too
    [array_geometry.csv, calibration_suite_cal_dump.txt]
2026-03-28 Freq Bandpass: freq ruler fixed to scale to match sliding window
    [calibration_suite_cal_dump.txt]
2026-03-28 Freq bandpass: sliding window has priority over red db line, red db line now acts as filter, red dot removed
    [calibration_suite_cal_dump.txt]
2026-03-30 Fixes: batt voltage json persistence with timestamps, mic gain persistence calib json, system settings scroll friction increased, wifi modal bigger keybaord, firmware flasher btn removed, radar UI bt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
    [array_geometry.csv, calibration_suite_cal_dump.txt]
2026-03-30 Batt voltage: battery_snapshot.json: not clobbered by default 25, will read last known voltage
2026-03-30 Radar: spin direction corrected, requires better calib or offset
    [config.py, magnetometer.py, main.py]
2026-03-30 Radar: XY plane correction with accurate yaw, addtional horizontal slider to adjust offset
    [config.py, config_persist.py, magnetometer.py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]
2026-03-30 Added FPS hud heatmap stability presets (sharp / balanced /smooth)
    [config.py, main.py]
2026-03-30 feat(dsp): improve multi-source heatmap — top-K, gamma, 2nd 2D MUSIC peak
2026-05-04 Final Presentation - Mini Version
    - kept thick backup
    - made all versions of the result files
    - added the airflow simulation CAD file
    - adjusted Pi and Power stands
    [BL_sink.step, BR_low_fan.step, Inverse_body_cut_for_airflow.FCStd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]
2026-05-04 Final Review
    - Finalized the last minor details
    - Remade new final result files with cuts made
    - removed other versions
    Note: If you made an edit to the actual CAD file and have trouble cutting the screw holes, then export that part of the housing, and in an empty file, copy paste that part along with the screws. Make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
    [BL_Sink.stl, BL_sink.step, BR_Low_Fan.stl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]
